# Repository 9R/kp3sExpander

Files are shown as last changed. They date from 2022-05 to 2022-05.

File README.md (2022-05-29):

# GPIO Expander for KP3S

This PCB is as a replacement for the original LCD-PCB of the KP3S and can be 
installed in the same location. It will expose additional GPIOs. It is meant
to be used with alternative firmware like klipper, where the original LCD-PCB 
can not be used.

## Features

* exposes SPI2 (can be used to connect a klipper compatible display)
* exposes 23 additional GPIOs
* access to 5V, 3.3V and GND to power additional, low current sensors
* the original flexible flat cable can be used to connect to the mainboard

## Required Parts

* 1x 32 pin FFC connector (bottom contact, 1mm pitch)

optional:
* pin/socket headers (2.54 pitch, 2x 6x2 + 1x 14x2 for full assembly)
* 15cm 32 pin flexible flat cable (pitch 1mm)

## Example Config

An example config for klipper with an SSD1306 OLED display and a rotary encoder 
can be found [here](https://github.com/9R/Klipper_KP3S).

## Manufacturing

Use [KiCAD](https://kicad.org) to generate production files for the manufacturer
of your choice.

## Pictures

#### Top
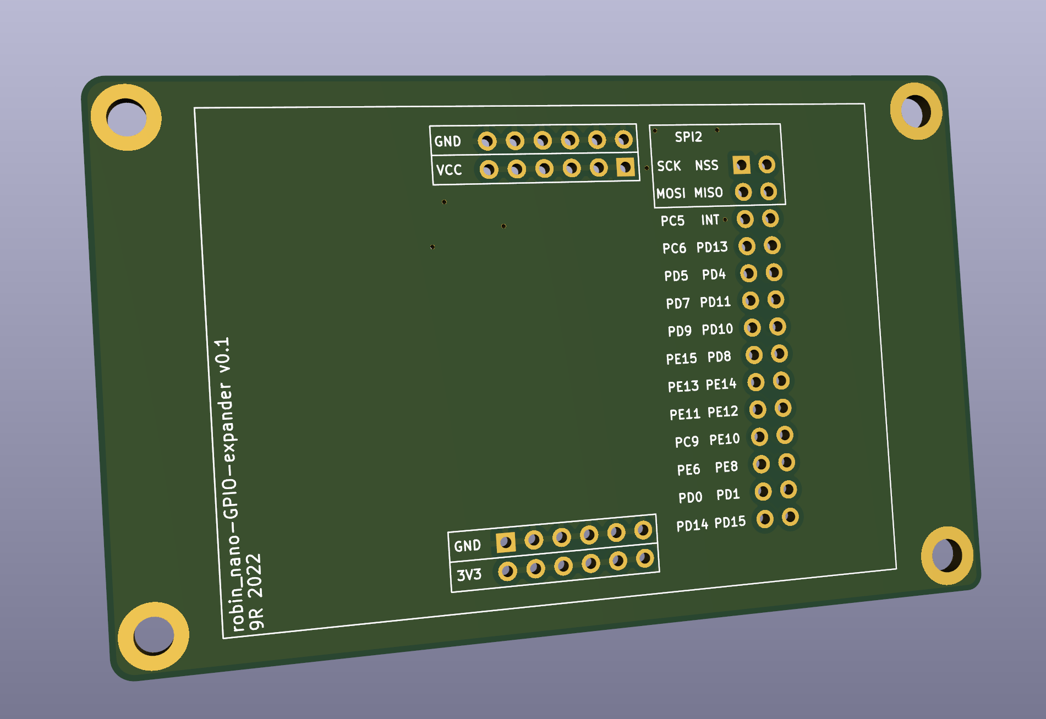
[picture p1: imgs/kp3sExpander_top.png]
top Top

#### Bottom
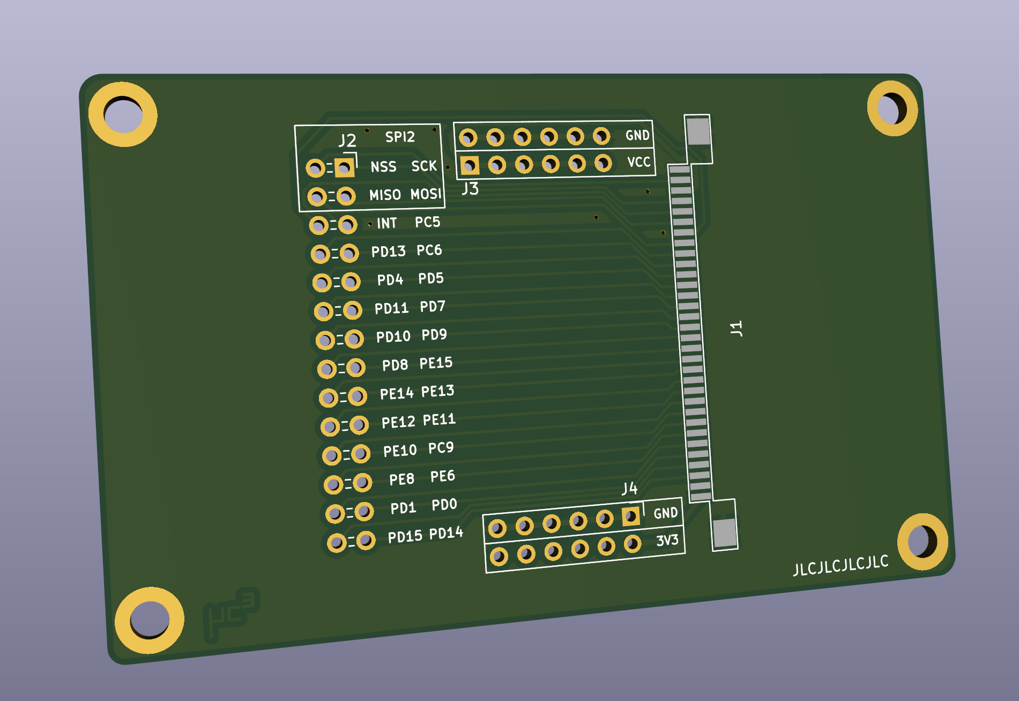
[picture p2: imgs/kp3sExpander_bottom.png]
bottom Bottom

#### Next to original LCD-PCB
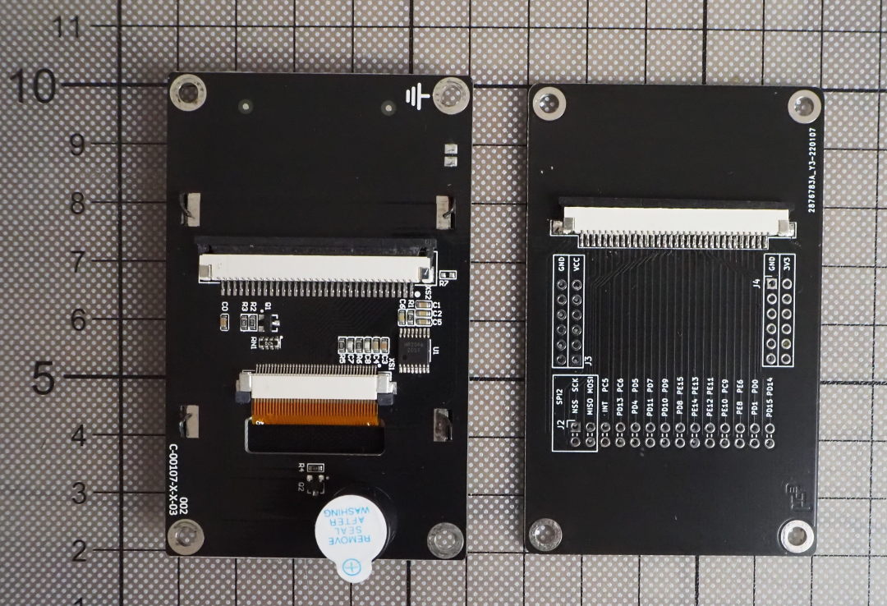
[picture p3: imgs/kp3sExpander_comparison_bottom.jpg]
comparison Next to original LCD-PCB

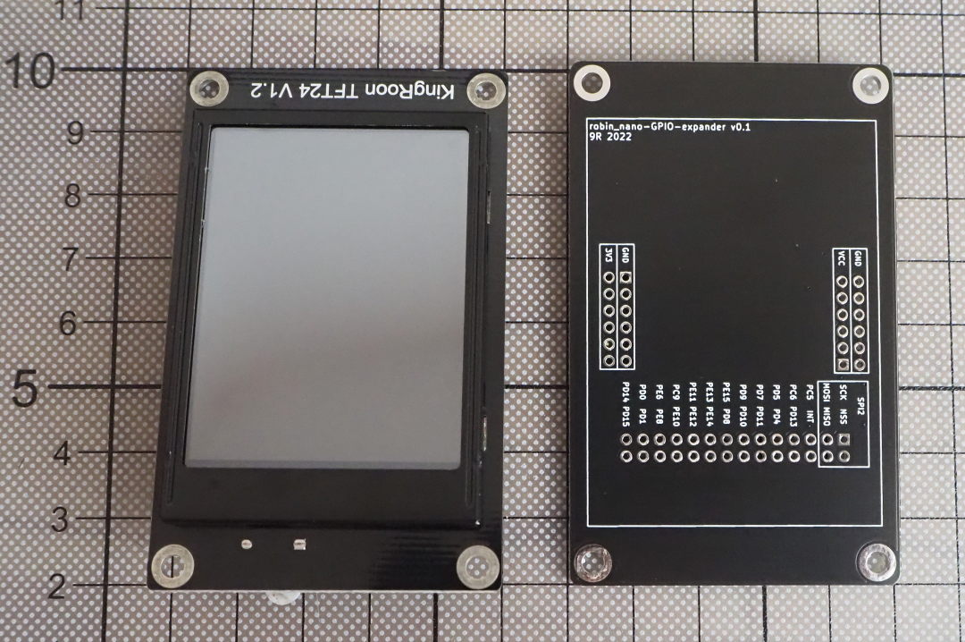
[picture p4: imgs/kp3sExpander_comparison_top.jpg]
comparison Next to original LCD-PCB

#### Installed in KP3S
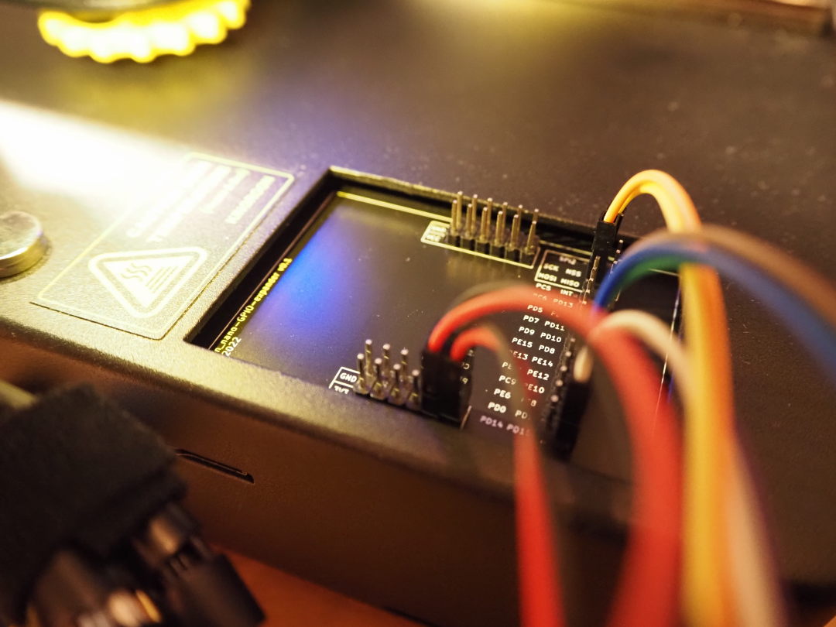
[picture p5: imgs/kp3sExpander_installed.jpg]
bottom Installed in KP3S


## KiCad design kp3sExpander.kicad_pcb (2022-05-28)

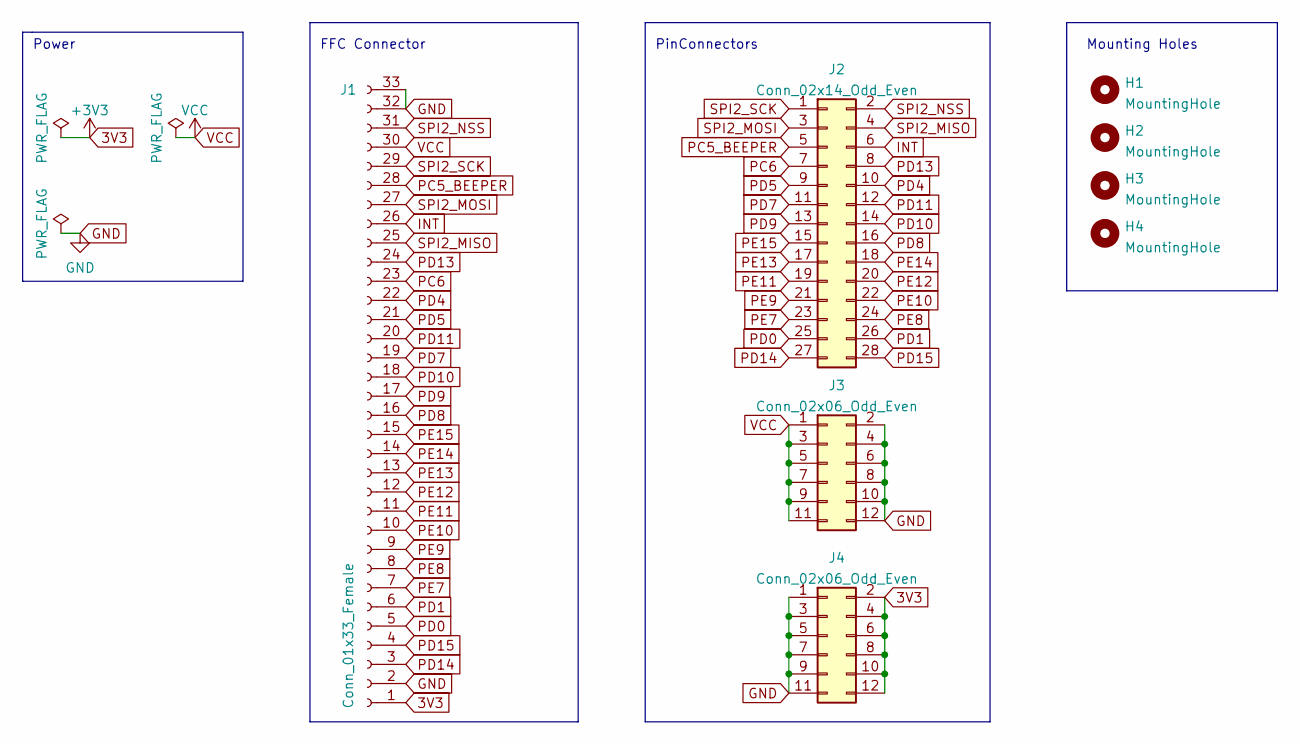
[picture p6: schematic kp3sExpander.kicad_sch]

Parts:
H1, H2, H3, H4: MountingHole; MountingHole_3.2mm_M3_DIN965_Pad
J1: Conn_01x33_Female; FPC_32
J2: Conn_02x14_Odd_Even; PinSocket_2x14_P2.54mm_Horizontal
J3, J4: Conn_02x06_Odd_Even; PinHeader_2x06_P2.54mm_Horizontal

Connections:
3V3: J1.1, J4.2, J4.4, J4.6, J4.8, J4.10, J4.12
GND: J1.2, J1.32, J1.33, J3.2, J3.4, J3.6, J3.8, J3.10, J3.12, J4.1, J4.3, J4.5, J4.7, J4.9, J4.11
INT: J1.26, J2.6
PC5_BEEPER: J1.28, J2.5
PC6: J1.23, J2.7
PD0: J1.5, J2.25
PD1: J1.6, J2.26
PD4: J1.22, J2.10
PD5: J1.21, J2.9
PD7: J1.19, J2.11
PD8: J1.16, J2.16
PD9: J1.17, J2.13
PD10: J1.18, J2.14
PD11: J1.20, J2.12
PD13: J1.24, J2.8
PD14: J1.3, J2.27
PD15: J1.4, J2.28
PE7: J1.7, J2.23
PE8: J1.8, J2.24
PE9: J1.9, J2.21
PE10: J1.10, J2.22
PE11: J1.11, J2.19
PE12: J1.12, J2.20
PE13: J1.13, J2.17
PE14: J1.14, J2.18
PE15: J1.15, J2.15
SPI2_MISO: J1.25, J2.4
SPI2_MOSI: J1.27, J2.3
SPI2_NSS: J1.31, J2.2
SPI2_SCK: J1.29, J2.1
VCC: J1.30, J3.1, J3.3, J3.5, J3.7, J3.9, J3.11

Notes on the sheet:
PinConnectors
Power
Mounting Holes
FFC Connector

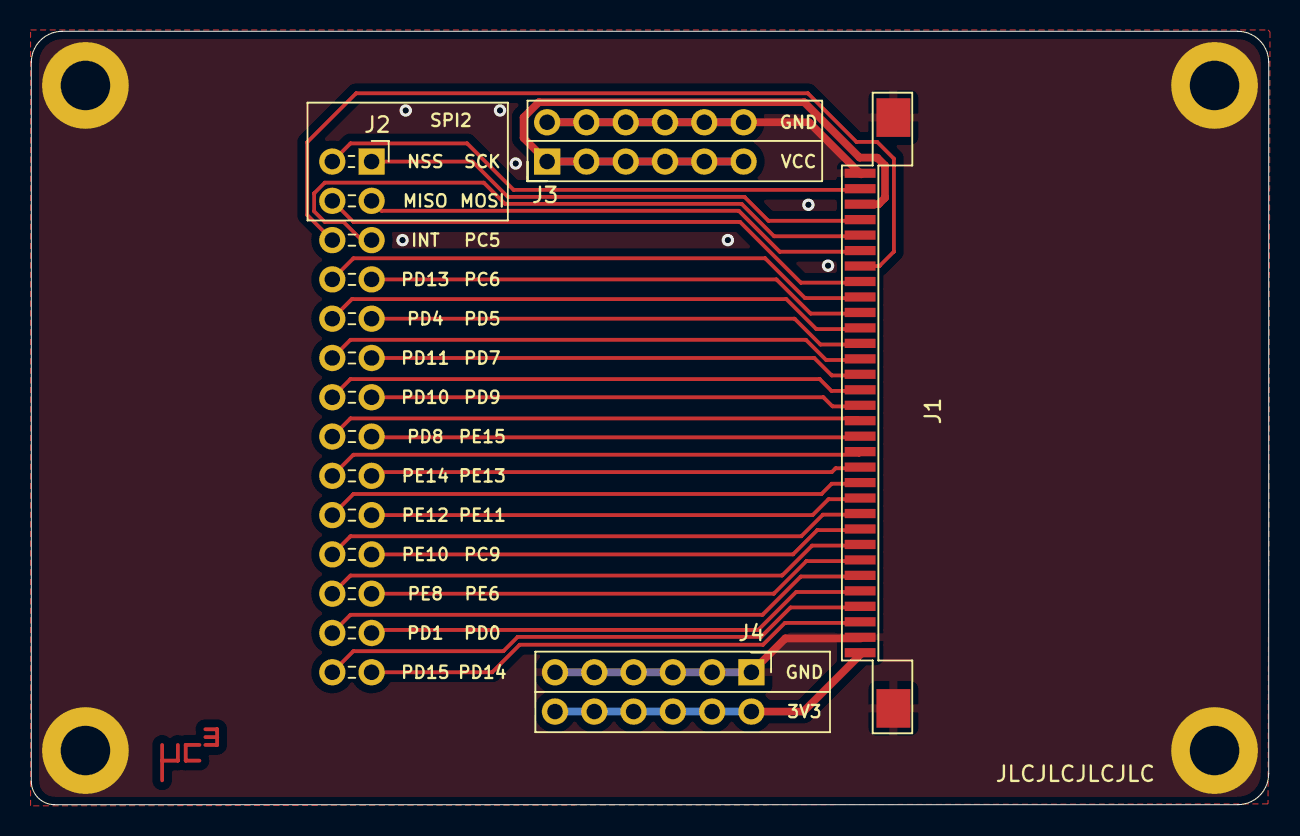
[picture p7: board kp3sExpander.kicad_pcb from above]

Board: 2 copper layers, 80.0 x 50.0 mm, 8 parts (0 on the bottom side), 31 nets.

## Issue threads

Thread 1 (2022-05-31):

Any idea on a klipper compatible screen that would be plug and play with this?

cfontes, 2022-05-31:
Hey this is very cool, I am about to install Klipper on mine and the TFT will be useless so this is nice for a Klipper Screen instalation.

What have you used yours to?

9R, 2022-10-12:
I use a ssd1306. You just have to make sure to get one with SPI interface, some are sold that only support i2c.

Please use my [klipper example config](https://github.com/9R/Klipper_KP3S/blob/main/display.cfg) as reference for how to connect an ssd1306.

Any other display with SPI interface from the official klipper documentation should also work

Closed 2023-03-27.
